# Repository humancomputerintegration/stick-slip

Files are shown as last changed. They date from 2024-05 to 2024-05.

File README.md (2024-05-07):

<p align="center">

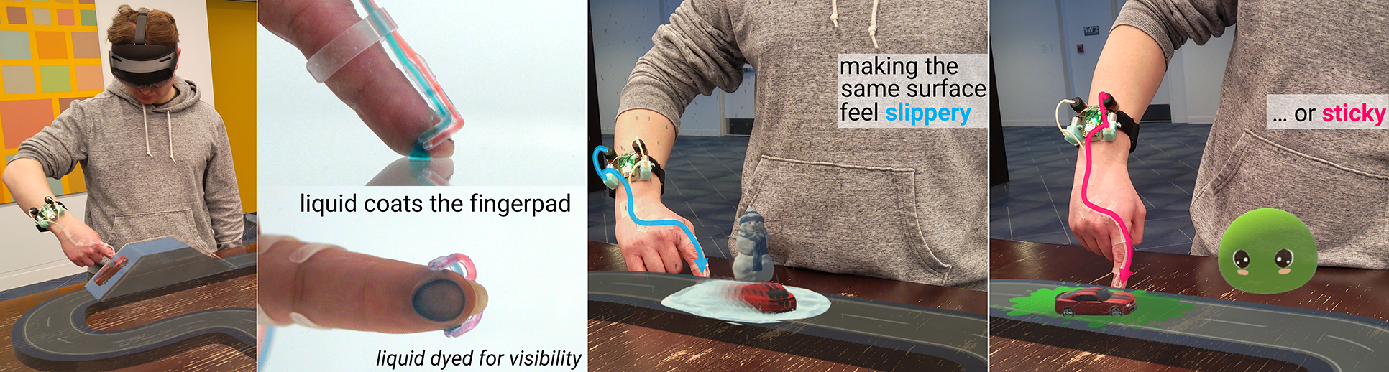
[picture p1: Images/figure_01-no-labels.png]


</p>

# Stick&Slip

This is a repository for the prototype Stick&Slip device created by Alex Mazursky, Jacob Serfaty, and Pedro Lopes at the University of Chicago's [Human Computer Integration Lab](https://lab.plopes.org/). Stick&Slip is a wearable approach to alter the friction of everyday objects using liquid coatings on the fingerpad!

## Repository Structure

* `Arduino` contains code for the microcontroller (ESP32).
* `PCB` contains the KICAD files for our custom PCB.
* `3D-prints` contains models for the wearable droplet generator and bracelet (.stl files). These can be printed with most SLA printers.

## Hardware

<p align="center">

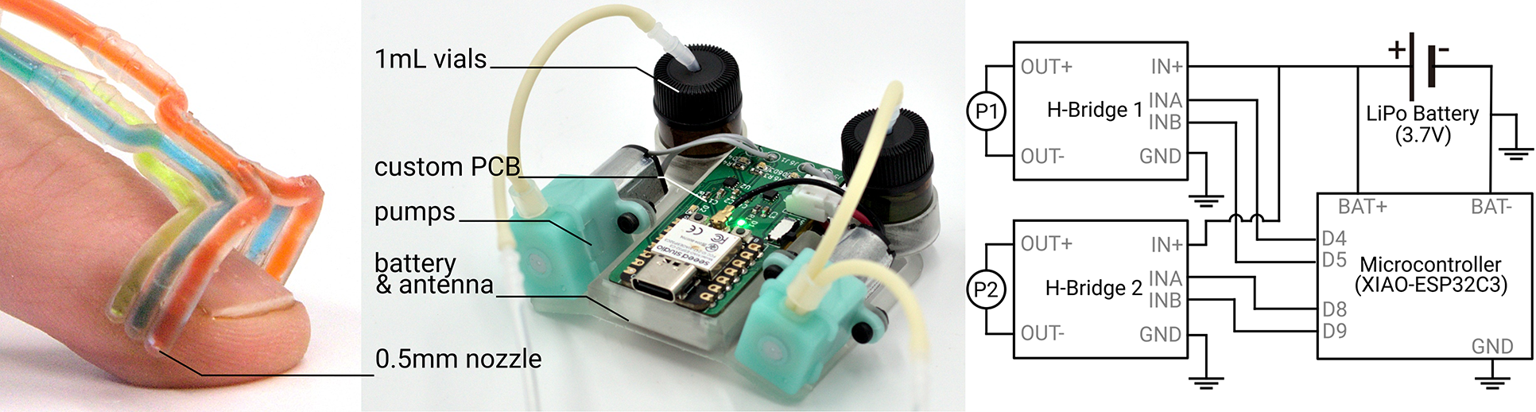
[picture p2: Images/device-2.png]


</p>

To reproduce our experience, we include the KiCad files to manufacture our delivery mechanism. In addition to the PCB and included SMT components, the device uses a Seeeduino Xiao ESP32C3 and two mini peristaltic pumps (Takasago Fluidic Systems, RP-Q) connected to thin silicone tubing (ID = 1 mm; OD = 2 mm) via barbed connectors. Each tube is then connected to the droplet generator.

## Citing

When using or building upon this device in an academic publication, please consider citing as follows:

Alex Mazursky, Jacob Serfaty, and Pedro Lopes. 2024. Stick&Slip: Altering Fingerpad Friction via Liquid Coatings. In Proceedings of the CHI Conference on Human Factors in Computing Systems (CHI ’24), May 11–16, 2024, Honolulu, HI, USA. ACM, New York, NY, USA, 14 pages. https://doi.org/10.1145/3613904.3642299

## Contact

For any questions about this repository, please contact alexmazursky@uchicago.edu

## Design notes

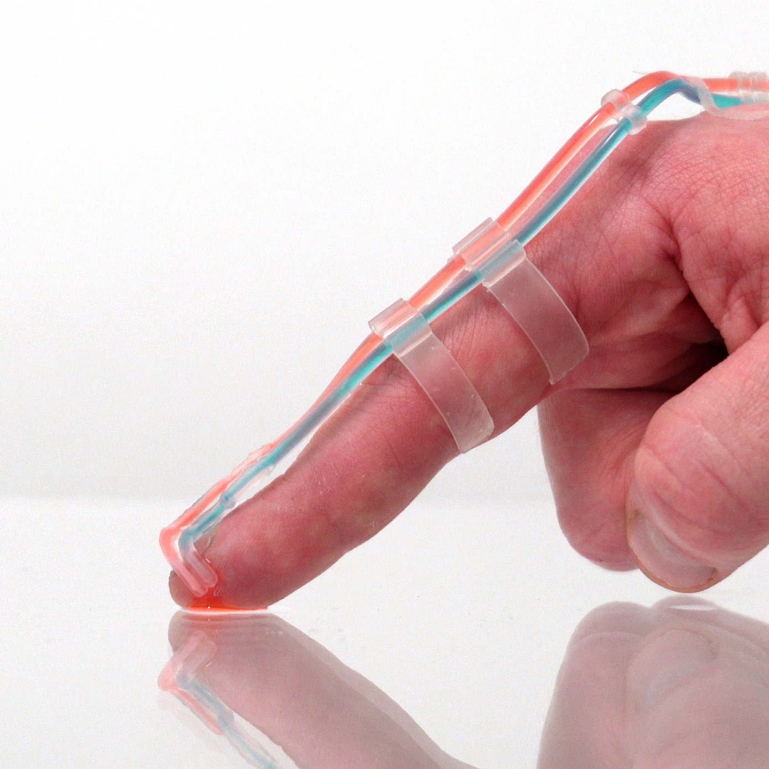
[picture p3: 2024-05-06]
Images/thumbnail_square_zoomed.png

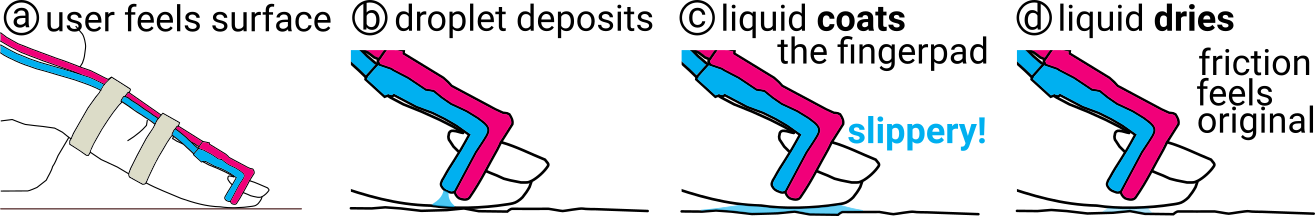
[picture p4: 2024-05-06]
Images/working-principle_larger-font.png

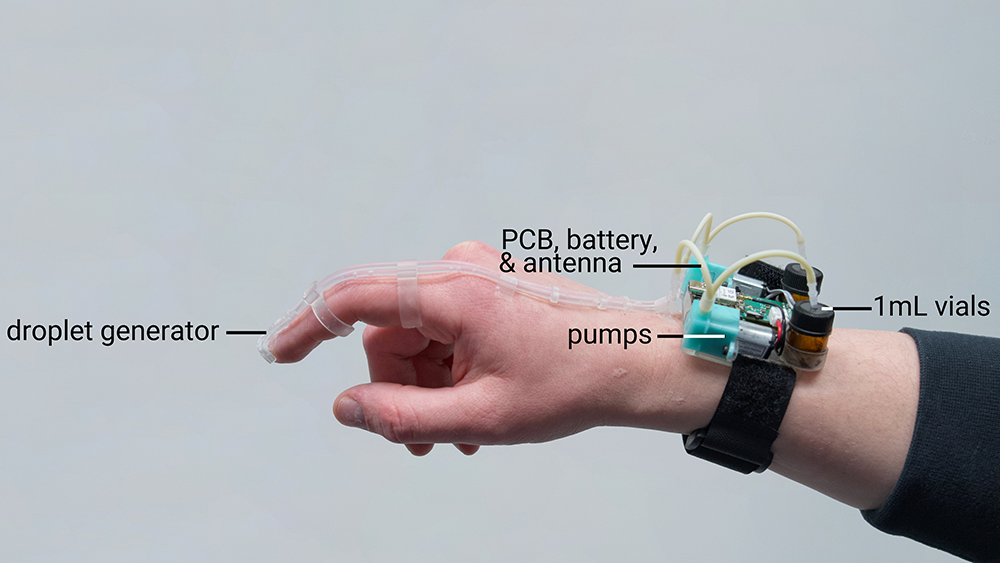
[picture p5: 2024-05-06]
Images/device-1.png

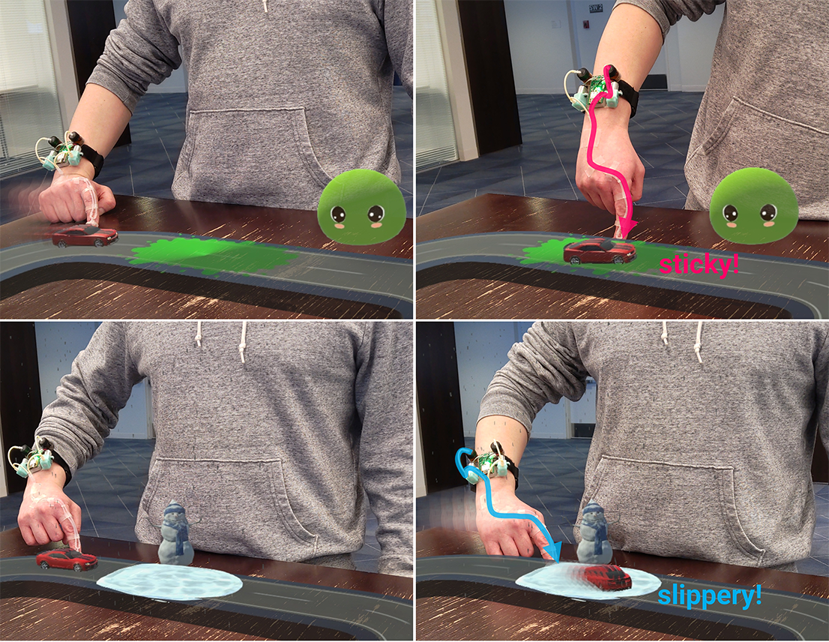
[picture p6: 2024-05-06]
Images/mixed-reality.png

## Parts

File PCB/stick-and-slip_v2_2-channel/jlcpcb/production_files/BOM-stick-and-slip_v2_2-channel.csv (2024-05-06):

Comment | Designator | Footprint | LCSC
LED | D4 | LED_0603_1608Metric
LED | D1 | LED_0603_1608Metric
1k | R3 | R_0603_1608Metric
Conn_01x01_Pin | J5 | TestPoint_Loop_D1.80mm_Drill1.0mm_Beaded
LED | D3 | LED_0603_1608Metric
LED | D2 | LED_0603_1608Metric
2_pin_jst | J9 | JST_PH_S2B-PH-K_1x02_P2.00mm_Horizontal
LED | D6 | LED_0603_1608Metric
Conn_01x01_Pin | J2 | TestPoint_Loop_D1.80mm_Drill1.0mm_Beaded
Conn_01x01_Pin | J6 | TestPoint_Loop_D1.80mm_Drill1.0mm_Beaded
1k | R1 | R_0603_1608Metric
0.1 uF | C2 | C_0603_1608Metric
1k | R6 | R_0603_1608Metric
-battery_xiao | J4 | TestPoint_Pad_1.0x1.0mm
0.1 uF | C1 | C_0603_1608Metric
DRV8837 | U2 | WSON-8-1EP_2x2mm_P0.5mm_EP0.9x1.6mm
Conn_01x01_Pin | J1 | TestPoint_Loop_D1.80mm_Drill1.0mm_Beaded
0.1 uF | C3 | C_0603_1608Metric
LED | D5 | LED_0603_1608Metric
DRV8837 | U3 | WSON-8-1EP_2x2mm_P0.5mm_EP0.9x1.6mm
MOUDLE-SEEEDUINO-XIAO-ESP32C3 | U1 | MOUDLE14P-SMD-2.54-21X17.8MM
SSSS810701 | S1 | SSSS810701
1k | R2 | R_0603_1608Metric
0.1 uF | C4 | C_0603_1608Metric
1k | R5 | R_0603_1608Metric
1k | R4 | R_0603_1608Metric
+battery_xiao | J3 | TestPoint_Pad_1.0x1.0mm

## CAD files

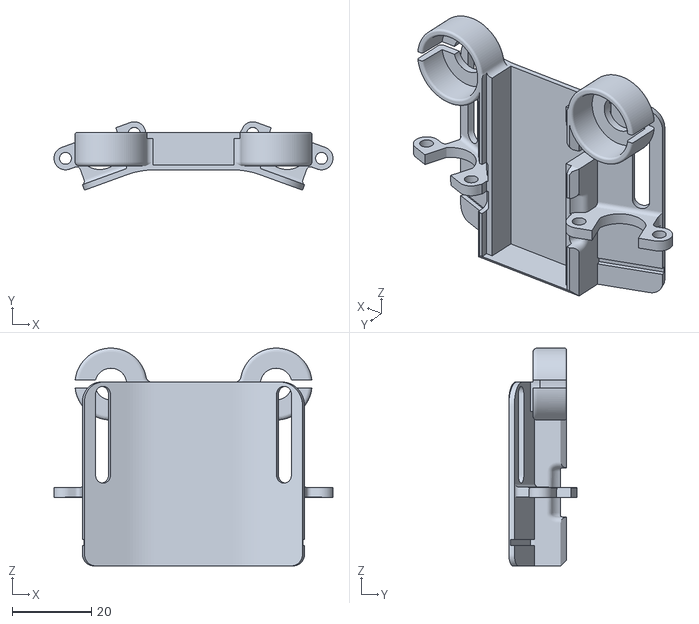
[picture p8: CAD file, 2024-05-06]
3D-prints/bracelet.stl
70.6 x 17.3 x 55.1

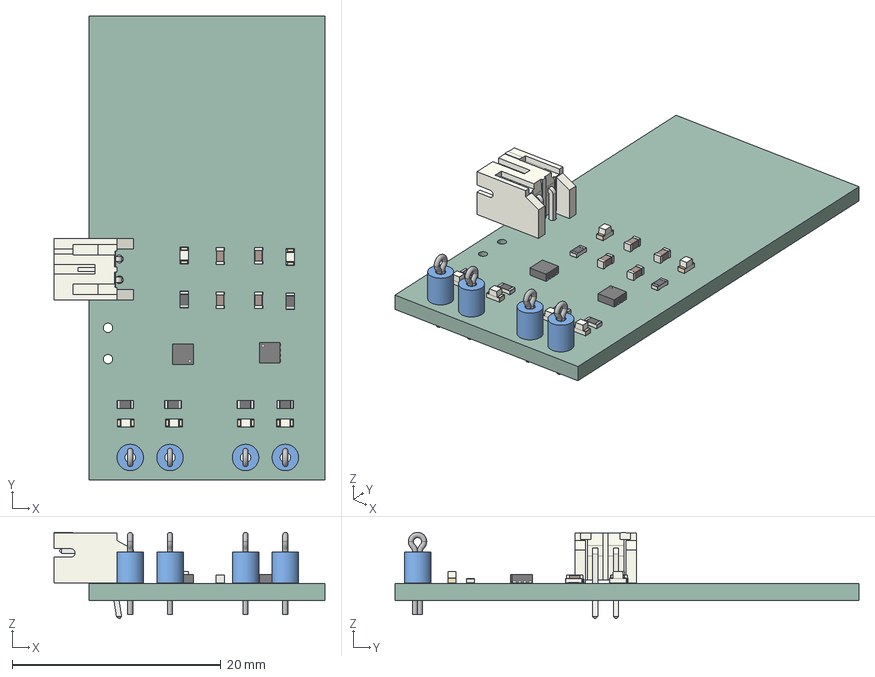
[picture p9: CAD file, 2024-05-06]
PCB/stick-and-slip_v2_2-channel/stick-and-slip_v2_2-channel.step
25.9 x 44.4 x 8.27 mm
PCB

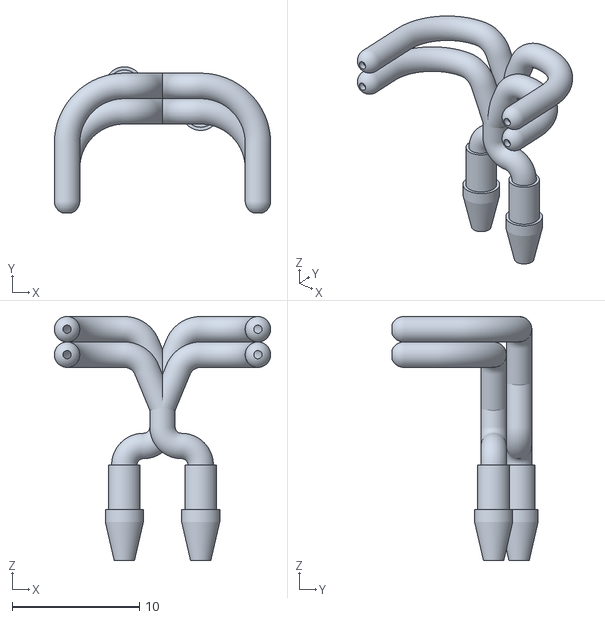
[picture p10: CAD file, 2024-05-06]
3D-prints/droplet-generator.stl
17.0 x 11.5 x 19.2

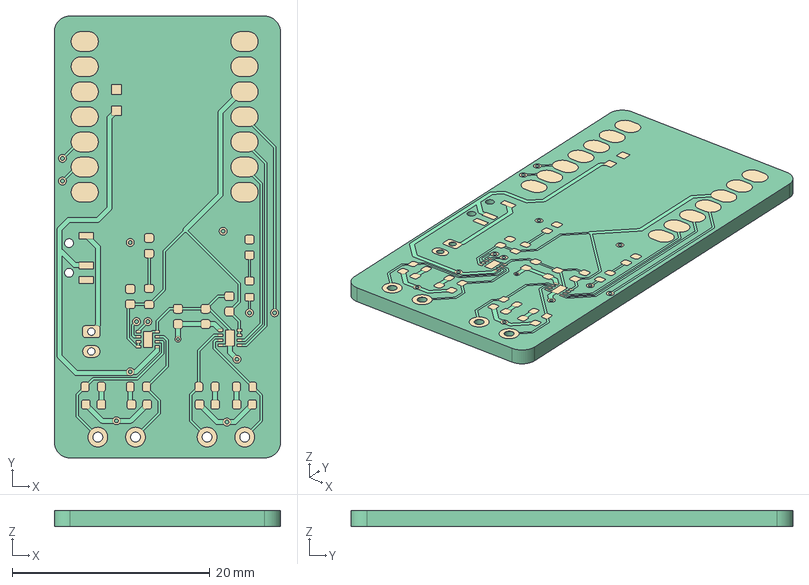
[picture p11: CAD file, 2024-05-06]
PCB/stick-and-slip_v2_2-channel/stick-and-slip_v2_2-channel_ksu.step
22.9 x 44.7 x 1.64 mm
Local_CS_1895
Pcb_1895
topPads_1895
topTracks_1895
botPads_1895
botTracks_1895

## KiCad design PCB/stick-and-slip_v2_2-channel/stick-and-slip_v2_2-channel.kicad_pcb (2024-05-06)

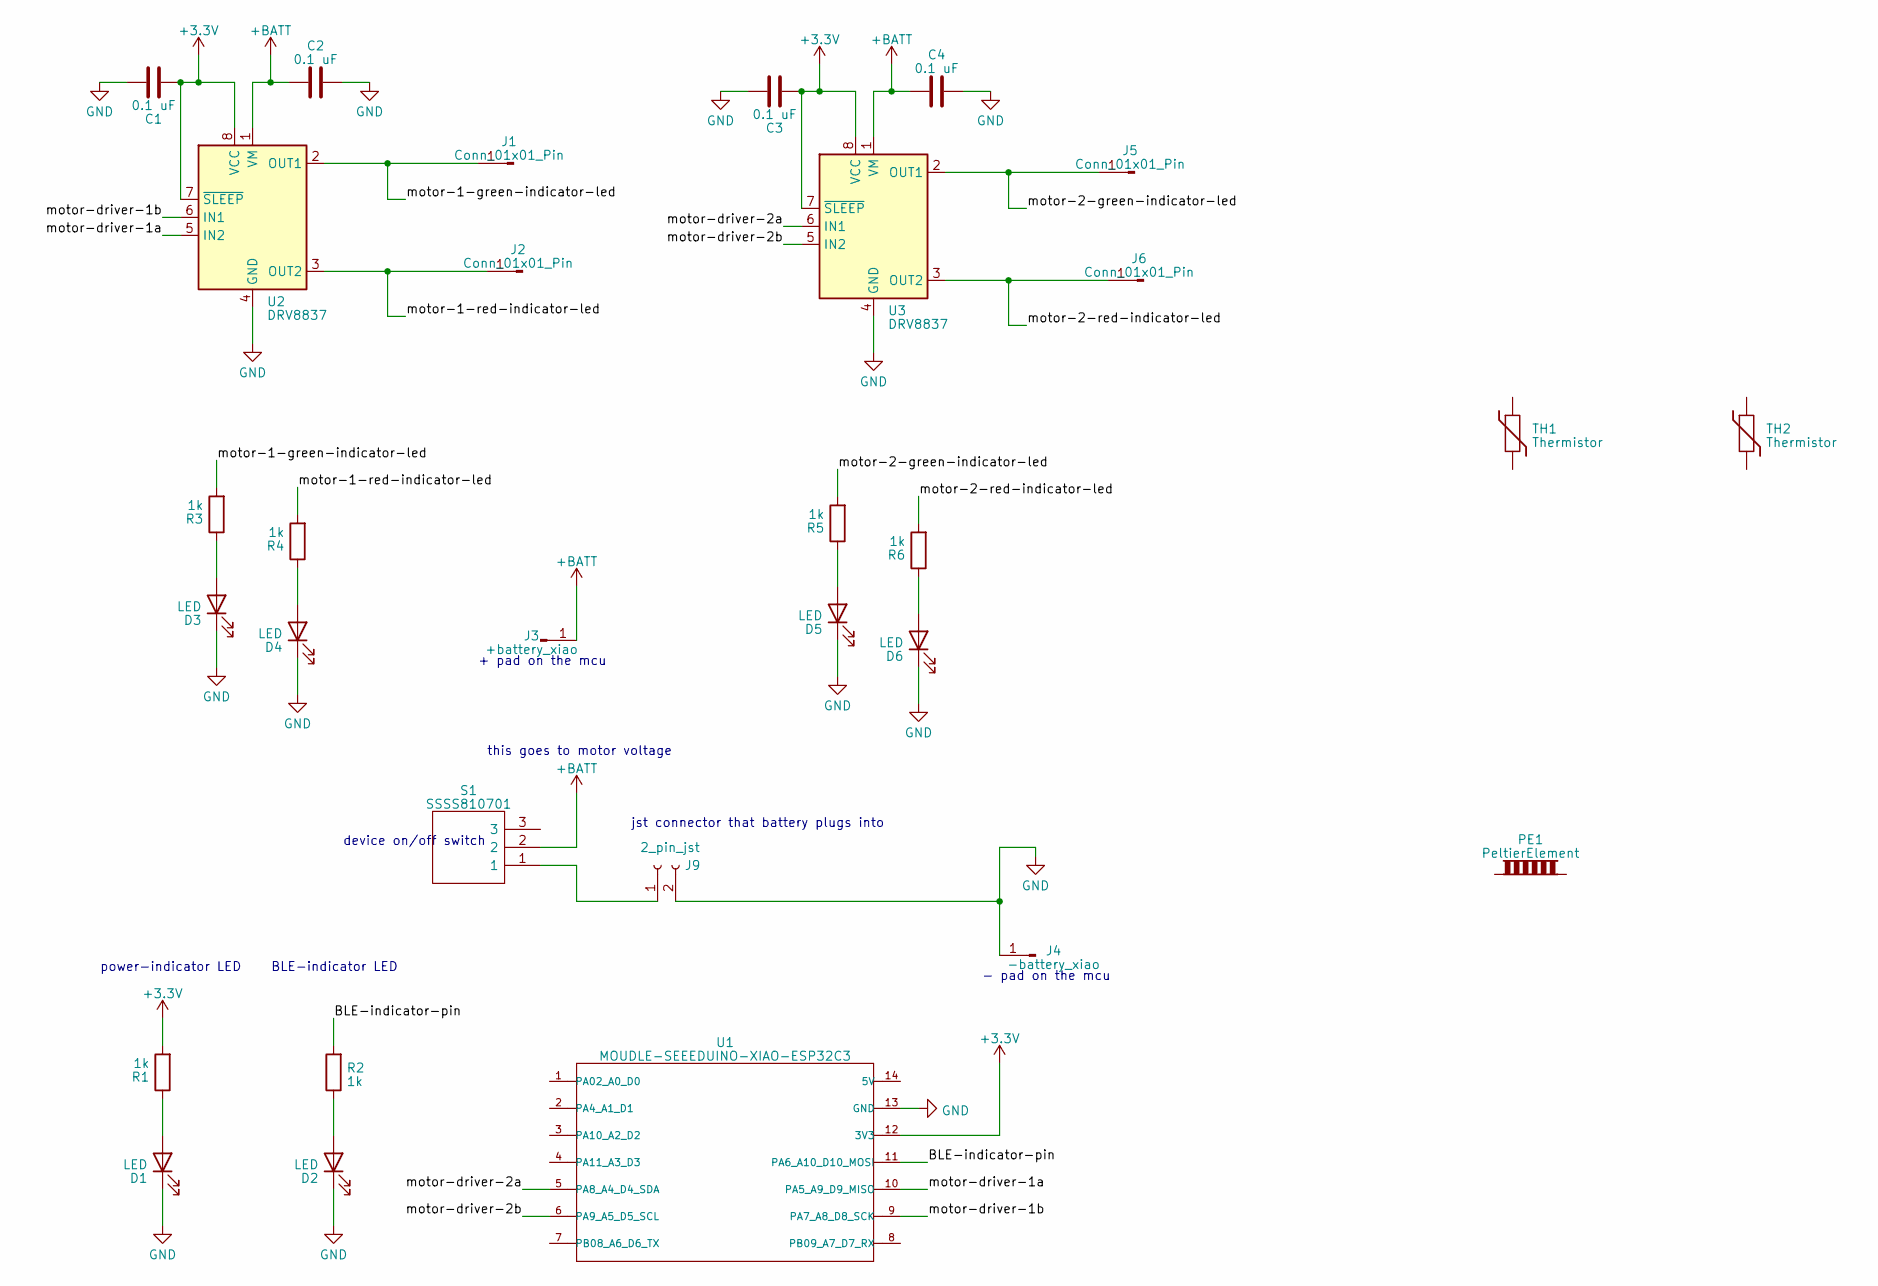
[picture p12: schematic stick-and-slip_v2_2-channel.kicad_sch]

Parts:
C1, C2, C3, C4: 0.1 uF; C_0603_1608Metric
D1, D2, D3, D4, D5, D6: LED; LED_0603_1608Metric
J1, J2, J5, J6: Conn_01x01_Pin; TestPoint_Loop_D1.80mm_Drill1.0mm_Beaded
J3: +battery_xiao; TestPoint_Pad_1.0x1.0mm
J4: -battery_xiao; TestPoint_Pad_1.0x1.0mm
J9: 2_pin_jst; JST_PH_S2B-PH-K_1x02_P2.00mm_Horizontal
PE1: PeltierElement
R1, R2, R3, R4, R5, R6: 1k; R_0603_1608Metric
S1: SSSS810701; Manufacturer_Part_Number SSSS810701; Mouser Part Number 688-SSSS810701
TH1, TH2: Thermistor
U1: MOUDLE-SEEEDUINO-XIAO-ESP32C3; MOUDLE14P-SMD-2.54-21X17.8MM
U2, U3: DRV8837; WSON-8-1EP_2x2mm_P0.5mm_EP0.9x1.6mm

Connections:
+3.3V: C1.1, C3.1, R1.2, U1.12 (3V3), U2.7 (~SLEEP), U2.8 (VCC), U3.7 (~SLEEP), U3.8 (VCC)
+BATT: C2.1, C4.1, J3.1, S1.2, U2.1 (VM), U3.1 (VM)
/BLE-indicator-pin: R2.2, U1.11 (PA6_A10_D10_MOSI)
/motor-1-green-indicator-led: J1.1, R3.2, U2.2 (OUT1)
/motor-1-red-indicator-led: J2.1, R4.2, U2.3 (OUT2)
/motor-2-green-indicator-led: J5.1, R5.2, U3.2 (OUT1)
/motor-2-red-indicator-led: J6.1, R6.2, U3.3 (OUT2)
/motor-driver-1a: U1.10 (PA5_A9_D9_MISO), U2.5 (IN2)
/motor-driver-1b: U1.9 (PA7_A8_D8_SCK), U2.6 (IN1)
/motor-driver-2a: U1.5 (PA8_A4_D4_SDA), U3.6 (IN1)
/motor-driver-2b: U1.6 (PA9_A5_D5_SCL), U3.5 (IN2)
GND: C1.2, C2.2, C3.2, C4.2, D1.1 (K), D2.1 (K), D3.1 (K), D4.1 (K), D5.1 (K), D6.1 (K), J4.1, J9.2, U1.13 (GND), U2.4 (GND), U2.9 (GND), U3.4 (GND), U3.9 (GND)
unnamed: D1.2 (A), R1.1
unnamed: D2.2 (A), R2.1
unnamed: D3.2 (A), R3.1
unnamed: D4.2 (A), R4.1
unnamed: D5.2 (A), R5.1
unnamed: D6.2 (A), R6.1
unnamed: J9.1, S1.1

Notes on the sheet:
- pad on the mcu
device on/off switch
this goes to motor voltage
BLE-indicator LED
power-indicator LED
jst connector that battery plugs into
+ pad on the mcu

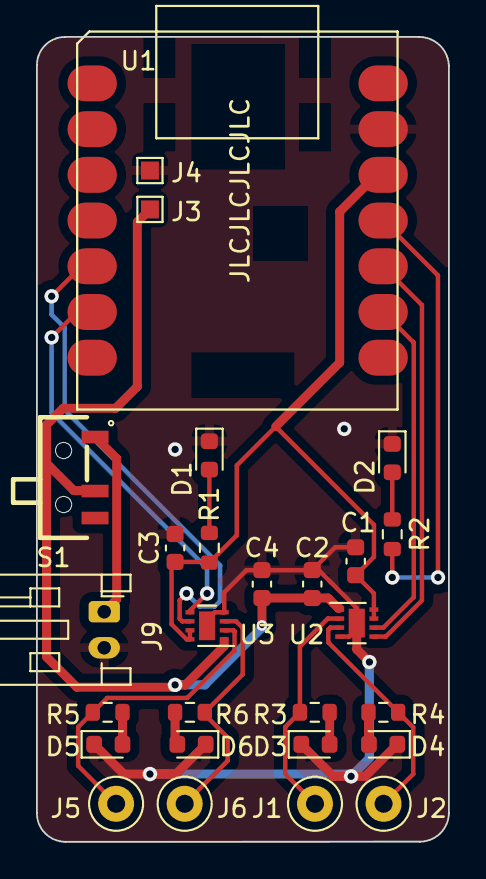
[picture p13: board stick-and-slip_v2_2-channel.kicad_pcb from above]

Board: 2 copper layers, 22.9 x 44.7 mm, 27 parts (0 on the bottom side), 19 nets.

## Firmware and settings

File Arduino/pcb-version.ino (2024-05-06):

// BLUETOOTH
#include <BLEDevice.h>
#include <BLEUtils.h>
#include <BLEServer.h>

// See the following for generating UUIDs:
// https://www.uuidgenerator.net/

#define SERVICE_UUID        "4fafc201-1fb5-459e-8fcc-c5c9c331914b"
#define CHARACTERISTIC_UUID "beb5483e-36e1-4688-b7f5-ea07361b26a8"

int led = D10;

// PUMPS
// pump 1
const int P1_inaPin = D8;
const int P1_inbPin = D9;

// pump 2
const int P2_inaPin = D4;
const int P2_inbPin = D5;

// pump 3
//const int P3_inaPin = D4;
//const int P3_inbPin = D2;


// comms
const byte numChars = 16;
char receivedChars[numChars];
char tempChars[numChars];        // temporary array for use when parsing
// variables to hold the parsed data
int trigger = 0;
int pumpNumber = 0;
int pumpTime = 0;

boolean newData = false;

unsigned long previousMillis = 0;
unsigned long currentMillis = 0;
unsigned long elapsedTime = 0;

class MyCallbacks: public BLECharacteristicCallbacks {
//    void onWrite(BLECharacteristic *pCharacteristic) {
//      std::string value = pCharacteristic->getValue();
//      int length = value.length();
//      if (length > 0) {
//        newData = true;
//        digitalWrite(led, HIGH);   // turn the LED on
//
//        //Serial.println("*********");
//        //Serial.print("New value: ");
//        for (int i = 0; i < length; i++) {
//          //Serial.print(value[i]);
//          receivedChars[i] = value[i];
//        }
//        //Serial.println();
//        //Serial.println("*********");
//
//      }
    void onWrite(BLECharacteristic *pCharacteristic) {
      std::string value = pCharacteristic->getValue();
      int length = value.length();
      if(length <= 0) {
        return;
      }
      newData = true;
      digitalWrite(led, HIGH);
      int crntNumChars = length <= (numChars - 1) ? length : (numChars - 1); // min(length, numChars - 1)
      strncpy(receivedChars, value.c_str(), crntNumChars);
      receivedChars[crntNumChars] = '\0';
    }
};

//============

void setup() {
  ////Serial.begin(115200);

  // Setup Bluetooth
  BLEDevice::init("StickSlipESP32");
  BLEServer *pServer = BLEDevice::createServer();

  BLEService *pService = pServer->createService(SERVICE_UUID);

  BLECharacteristic *pCharacteristic = pService->createCharacteristic(
                                         CHARACTERISTIC_UUID,
                                         BLECharacteristic::PROPERTY_READ |
                                         BLECharacteristic::PROPERTY_WRITE
                                       );

  pCharacteristic->setCallbacks(new MyCallbacks());

  pCharacteristic->setValue("Hello World");
  pService->start();

  BLEAdvertising *pAdvertising = pServer->getAdvertising();
  pAdvertising->start();

  pinMode(led, OUTPUT);

  // Setup Pumps
  // setup pump 1
  pinMode(P1_inaPin, OUTPUT);
  pinMode(P1_inbPin, OUTPUT);

  // setup pump 2
  pinMode(P2_inaPin, OUTPUT);
  pinMode(P2_inbPin, OUTPUT);

  // setup pump 3
  //pinMode(P3_inaPin, OUTPUT);
  //pinMode(P3_inbPin, OUTPUT);

}

//============

void loop() {
  if (newData == true) {
    strcpy(tempChars, receivedChars);
    // this temporary copy is necessary to protect the original data
    //   because strtok() used in parseData() replaces the commas with \0
    parseData();
    showParsedData();
    newData = false;
    digitalWrite(led, LOW);   // turn the LED off
    runPumps();
  }
}

//============

void runPumps() {
  //currentMillis = millis();
  //elapsedTime = currentMillis - previousMillis;
  ////Serial.println(elapsedTime);

  if (trigger == 0) {
    switch (abs(pumpNumber)) {
      case 1:
        if (pumpNumber < 0) {
          digitalWrite(P1_inbPin, HIGH);
          delay(pumpTime);
          digitalWrite(P1_inbPin, LOW);
        } else {
          digitalWrite(P1_inaPin, HIGH);
          delay(pumpTime);
          digitalWrite(P1_inaPin, LOW);
        }
        break;

      case 2:
        if (pumpNumber < 0) {
          digitalWrite(P2_inbPin, HIGH);
          delay(pumpTime);
          digitalWrite(P2_inbPin, LOW);
        } else {
          digitalWrite(P2_inaPin, HIGH);
          delay(pumpTime);
          digitalWrite(P2_inaPin, LOW);
        }
        break;

/*
      case 3:
        if (pumpNumber < 0) {
          digitalWrite(P3_inbPin, HIGH);
          delay(pumpTime);
          digitalWrite(P3_inbPin, LOW);
        } else {
          digitalWrite(P3_inaPin, HIGH);
          delay(pumpTime);
          digitalWrite(P3_inaPin, LOW);
        }
        break;
*/
      default:
        digitalWrite(P1_inaPin, LOW);
        digitalWrite(P1_inbPin, LOW);
        digitalWrite(P2_inaPin, LOW);
        digitalWrite(P2_inbPin, LOW);
        //digitalWrite(P3_inaPin, LOW);
        //digitalWrite(P3_inbPin, LOW);
        break;
    }
  }

  else if (trigger == 1) {
    switch (abs(pumpNumber)) {
      case 1:
        if (pumpTime == 0) {
          digitalWrite(P1_inaPin, LOW);
        } else {
          digitalWrite(P1_inaPin, HIGH);
        }
        break;

      case 2:
        if (pumpTime == 0) {
          digitalWrite(P2_inaPin, LOW);
        } else {
          digitalWrite(P2_inaPin, HIGH);
        }
        break;

/*      case 3:
        if (pumpTime == 0) {
          digitalWrite(P3_inaPin, LOW);
        } else {
          digitalWrite(P3_inaPin, HIGH);
        }
        break;
*/
      default:
        digitalWrite(P1_inaPin, LOW);
        digitalWrite(P1_inbPin, LOW);
        digitalWrite(P2_inaPin, LOW);
        digitalWrite(P2_inbPin, LOW);
        //digitalWrite(P3_inaPin, LOW);
        //digitalWrite(P3_inbPin, LOW);
        break;
    }
  }
}


//============

void parseData() {      // split the data into its parts

  char * strtokIndx; // this is used by strtok() as an index

  strtokIndx = strtok(tempChars, ",");
  trigger = atoi(strtokIndx);

  strtokIndx = strtok(NULL, ",");
  pumpNumber = atoi(strtokIndx);

  strtokIndx = strtok(NULL, ","); // this continues where the previous call left off
  pumpTime = atoi(strtokIndx);     // convert this part to an integer

  //    strtokIndx = strtok(NULL, ","); // this continues where the previous call left off
  //    P2_pwm = atoi(strtokIndx);     // convert this part to an integer
  //
  //    strtokIndx = strtok(NULL, ","); // this continues where the previous call left off
  //    P2_time = atoi(strtokIndx);     // convert this part to an integer
  //
  //    strtokIndx = strtok(NULL, ","); // this continues where the previous call left off
  //    P3_pwm = atoi(strtokIndx);     // convert this part to an integer
  //
  //    strtokIndx = strtok(NULL, ","); // this continues where the previous call left off
  //    P3_time = atoi(strtokIndx);     // convert this part to an integer

}

//============

void showParsedData() {
  //Serial.print("mode: ");
  //Serial.println(trigger);
  //Serial.print("pump number: ");
  //Serial.println(pumpNumber);
  //Serial.print("pump time: ");
  //Serial.println(pumpTime);
  //    //Serial.print("P2_pwm ");
  //    //Serial.println(P2_pwm);
  //    //Serial.print("P2_time ");
  //    //Serial.println(P2_time);
  //    //Serial.print("P3_pwm ");
  //    //Serial.println(P3_pwm);
  //    //Serial.print("P3_time ");
  //    //Serial.println(P3_time);
}

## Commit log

2024-05-06 cleaning repo
    [Cone.obj, Oculus_IAP.tsv, aloe.obj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]
2024-05-06 Code for the ESP32 XIAO.
2024-05-06 Populating folders with code, cad, and images.
    [BOM-stick-and-slip_v2_2-channel.csv, bracelet.stl, droplet-generator.stl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]
